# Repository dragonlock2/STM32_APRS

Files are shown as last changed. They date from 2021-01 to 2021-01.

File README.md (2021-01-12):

# STM32 APRS

APRS modulation and demodulation with a UI. Made for STM32L433.

https://matthewtran.dev/2021/01/stm32-aprs/

Potentially reusable modules (.c/.h) in Core/:
* BitFIFO/IntFIFO - FIFO queue implemented with a ring buffer
* SSD1306 - I2C driver for SSD1306 OLED w/ compact font
* Keyboard - ASCII keyboard using T9 button layout
* AFSK - High speed AFSK modulation and demodulation to and from bit streams
* APRS - High speed APRS packet generation and decoding to and from bit streams
* APRSGUI - TUI implementation for displaying and configuring APRS packets

## How to Use

### iPython

ipython/aprs.ipynb is a Python implementation of the APRS encoding and decoding algorithms written for easy conversion to C.

### KiCad

The PCB design files for the hardware are located in kicad/.

### STM32CubeIDE

APRSTest.ioc is a STM32CubeMX configuration file and was used to generate the project starter code in STM32CubeIDE. Everything in Core/ should be copied over to the generated Core/ folder, overwriting as necessary.

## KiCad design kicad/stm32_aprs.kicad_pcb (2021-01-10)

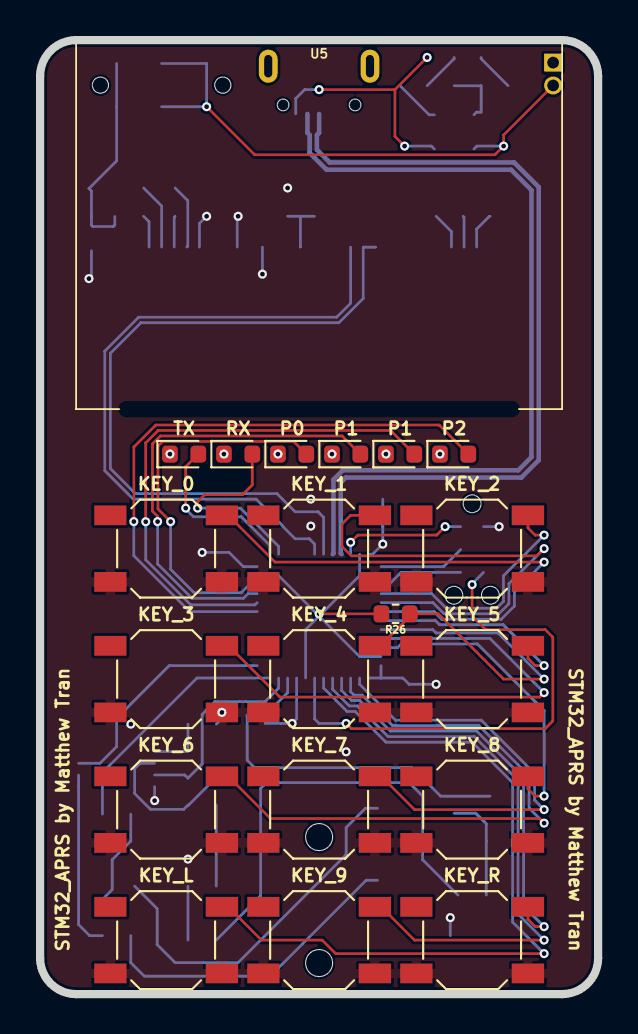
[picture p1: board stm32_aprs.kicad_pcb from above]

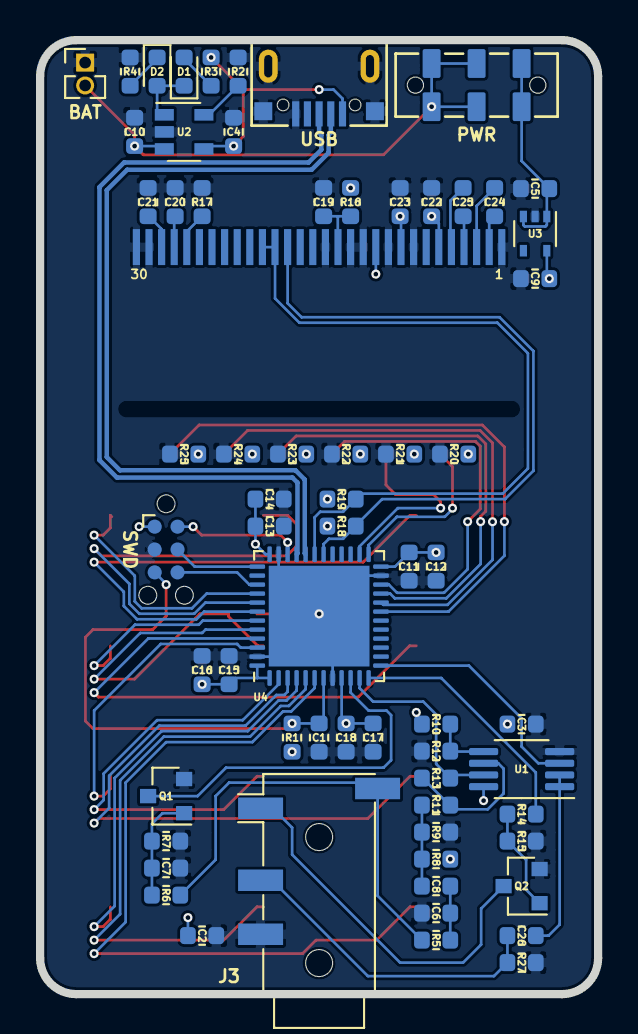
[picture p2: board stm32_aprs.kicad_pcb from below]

Board: 2 copper layers, 31.0 x 53.0 mm, 85 parts (65 on the bottom side), 63 nets.

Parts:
BAT: BAT; PinHeader_1x02_P1.27mm_Vertical
C1, C3, C6, C11, C13, C15, C17, C19: 100n; C_0603_1608Metric
C2, C4, C7, C10, C26: 10u; C_0603_1608Metric
C5, C8, C9, C12, C14, C16, C18, C20, C21, C22, C23, C24, C25: 1u; C_0603_1608Metric
D1: CHRG; LED_0603_1608Metric
D2: FULL; LED_0603_1608Metric
J3: Baofeng; Jack_3.5mm_PJ320D_Horizontal
KEY_0: KEY_0; SW_SPST_SKQG_WithoutStem
KEY_1: KEY_1; SW_SPST_SKQG_WithoutStem
KEY_2: KEY_2; SW_SPST_SKQG_WithoutStem
KEY_3: KEY_3; SW_SPST_SKQG_WithoutStem
KEY_4: KEY_4; SW_SPST_SKQG_WithoutStem
KEY_5: KEY_5; SW_SPST_SKQG_WithoutStem
KEY_6: KEY_6; SW_SPST_SKQG_WithoutStem
KEY_7: KEY_7; SW_SPST_SKQG_WithoutStem
KEY_8: KEY_8; SW_SPST_SKQG_WithoutStem
KEY_9: KEY_9; SW_SPST_SKQG_WithoutStem
KEY_L: KEY_L; SW_SPST_SKQG_WithoutStem
KEY_R: KEY_R; SW_SPST_SKQG_WithoutStem
P0: LED0; LED_0603_1608Metric
P1: LED2; LED_0603_1608Metric
P1#2: LED1; LED_0603_1608Metric
P2: LED3; LED_0603_1608Metric
PWR: PWR_SW; JS202011JAQN
Q1, Q2: DMG2302U; SOT-23
R1, R6, R10, R11, R12, R15, R16, R26: 10k; R_0603_1608Metric
R2, R3, R4, R18, R19, R27: 2.2k; R_0603_1608Metric
R5: 470; R_0603_1608Metric
R7: 22k; R_0603_1608Metric
R8, R9, R20, R21, R22, R23, R24, R25: 1k; R_0603_1608Metric
R13: 47k; R_0603_1608Metric
R14: 22; R_0603_1608Metric
R17: 470k; R_0603_1608Metric
RX: RX; LED_0603_1608Metric
SWD: SWD; Tag-Connect_TC2030-IDC-NL_2x03_P1.27mm_Vertical
TX: TX; LED_0603_1608Metric
U1: MCP6L02x-xMS; MSOP-8_3x3mm_P0.65mm
U2: MCP73831-2-OT; SOT-23-5
U3: MIC5365-3.3YC5; SOT-353_SC-70-5
U4: STM32L433CCUx; QFN-48-1EP_7x7mm_P0.5mm_EP5.6x5.6mm
U5: SSD1306
USB: USB_B_Micro; U254-051N-4BH83-F1B

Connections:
+3V3: C2.2, C3.2, C9.1, C11.1, C12.1, C13.1, C14.1, C15.1, C16.1, C17.1, C18.1, C22.1, C23.1, KEY_0.2, KEY_1.2, KEY_2.2, KEY_3.2, KEY_4.2, KEY_5.2, KEY_6.2, KEY_7.2, KEY_8.2, KEY_9.2, KEY_L.2, KEY_R.2, R1.1, R8.1, R10.2, R16.1, R18.1, R19.1, SWD.1, U1.8, U3.5, U4.1, U4.9, U4.24, U4.36, U4.48, U5.6, U5.9, U5.11
+3V8: BAT.2, C10.1, PWR.2, PWR.3, PWR.5, PWR.6, U2.3
+5V: C4.2, R3.1, U2.4, USB.1
/ADC_IN: R13.1, U1.7, U4.11
/AUDIO_IN: J3.S, R5.2, R6.2
/AUDIO_OUT: C26.1, J3.R1, R27.1
/BOOT0_KEY_4: KEY_4.1, R26.1, U4.44
/DAC_OUT: U1.3, U4.13
/KEY_0: KEY_0.1, U4.42
/KEY_1: KEY_1.1, U4.41
/KEY_2: KEY_2.1, U4.40
/KEY_3: KEY_3.1, U4.45
/KEY_5: KEY_5.1, U4.43
/KEY_6: KEY_6.1, U4.3
/KEY_7: KEY_7.1, U4.2
/KEY_8: KEY_8.1, U4.46
/KEY_9: KEY_9.1, U4.5
/KEY_L: KEY_L.1, U4.6
/KEY_R: KEY_R.1, U4.4
/LED_0: P0.2, U4.22
/LED_1: P1#2.2, U4.21
/LED_2: P1.2, U4.20
/LED_3: P2.2, U4.19
/NRST: C1.1, R1.2, SWD.5, U4.7
/PTT: J3.T, Q2.3
/RX_DET: Q1.3, U4.10
/RX_LED: RX.2, U4.26
/SCL: R18.2, U4.30, U5.18
/SDA: R19.2, U4.31, U5.19, U5.20
/SWCLK: SWD.4, U4.37
/SWDIO: SWD.2, U4.34
/SWO: SWD.6, U4.39
/TX_LED: TX.2, U4.25
/TX_PTT: R14.2, U4.12
/USB_N: U4.32, USB.2
/USB_P: U4.33, USB.3
GND: BAT.1, C1.2, C2.1, C3.1, C4.1, C5.1, C6.2, C7.2, C9.2, C10.2, C11.2, C12.2, C13.2, C14.2, C15.2, C16.2, C17.2, C18.2, C19.2, C20.2, C21.2, C22.2, C23.2, J3.R2, Q1.2, Q2.2, R2.2, R4.1, R7.2, R9.2, R12.1, R15.2, R17.2, R20.1, R21.1, R22.1, R23.1, R24.1, R25.1, R26.2, R27.2, SWD.3, U1.4, U2.2, U3.2, U4.8, U4.23, U4.35, U4.47, U4.49, U5.1, U5.8, U5.10, U5.12, U5.13, U5.15, U5.29, U5.30, USB.5, USB.6
unnamed: C5.2, PWR.1, PWR.4, U3.1, U3.3
unnamed: C6.1, C8.2, R5.1
unnamed: C7.1, Q1.1, R6.1, R7.1
unnamed: C8.1, R8.2, R9.1, R11.2
unnamed: C19.1, R16.2, U5.14
unnamed: C20.1, U5.27
unnamed: C21.1, U5.28
unnamed: C24.1, U5.2
unnamed: C24.2, U5.3
unnamed: C25.1, U5.4
unnamed: C25.2, U5.5
unnamed: C26.2, U1.1, U1.2
unnamed: D1.1, D2.2, U2.1
unnamed: D1.2, R3.2
unnamed: D2.1, R4.2
unnamed: R20.2, TX.1
unnamed: R21.2, RX.1
unnamed: P0.1, R22.2
unnamed: P1#2.1, R23.2
unnamed: P1.1, R24.2
unnamed: P2.1, R25.2
unnamed: Q2.1, R14.1, R15.1
unnamed: R2.1, U2.5
unnamed: R10.1, R12.2, U1.5
unnamed: R11.1, R13.2, U1.6
unnamed: R17.1, U5.26

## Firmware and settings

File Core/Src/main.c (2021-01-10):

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
/* Includes ------------------------------------------------------------------*/
#include "main.h"
#include "usb_device.h"

/* USER CODE BEGIN Includes */

#include "stdio.h"
#include "usbd_cdc_if.h"

#include "BitFIFO.h"
#include "AFSK.h"
#include "APRS.h"
#include "SSD1306.h"
#include "APRSGUI.h"
#include "Keyboard.h"

/* USER CODE END Includes */

ADC_HandleTypeDef hadc1;
DMA_HandleTypeDef hdma_adc1;

DAC_HandleTypeDef hdac1;
DMA_HandleTypeDef hdma_dac_ch1;

I2C_HandleTypeDef hi2c1;
DMA_HandleTypeDef hdma_i2c1_tx;

OPAMP_HandleTypeDef hopamp1;

RNG_HandleTypeDef hrng;

TIM_HandleTypeDef htim2;
TIM_HandleTypeDef htim6;
TIM_HandleTypeDef htim7;

void SystemClock_Config(void);
static void MX_GPIO_Init(void);
static void MX_DMA_Init(void);
static void MX_DAC1_Init(void);
static void MX_TIM6_Init(void);
static void MX_ADC1_Init(void);
static void MX_OPAMP1_Init(void);
static void MX_RNG_Init(void);
static void MX_TIM2_Init(void);
static void MX_TIM7_Init(void);
static void MX_I2C1_Init(void);
/**
  * @brief  The application entry point.
  * @retval int
  */
int main(void)
{
  /* MCU Configuration--------------------------------------------------------*/

  /* Reset of all peripherals, Initializes the Flash interface and the Systick. */
  HAL_Init();

  /* Configure the system clock */
  SystemClock_Config();

  /* Initialize all configured peripherals */
  MX_GPIO_Init();
  MX_DMA_Init();
  MX_DAC1_Init();
  MX_TIM6_Init();
  MX_ADC1_Init();
  MX_OPAMP1_Init();
  MX_RNG_Init();
  MX_TIM2_Init();
  MX_TIM7_Init();
  MX_I2C1_Init();
  MX_USB_DEVICE_Init();
  /* USER CODE BEGIN 2 */

  HAL_OPAMP_Start(&hopamp1);
  AFSK_init();
  APRS_init();

  SSD1306_init();
  APRSGUI_init(&APRS_DEFAULT_PACKET);
  HAL_TIM_Base_Start_IT(&htim7); // update display at ~24FPS

  /* USER CODE END 2 */

  /* Infinite loop */
  /* USER CODE BEGIN WHILE */

  while (1)
  {
    /* USER CODE END WHILE */

    /* USER CODE BEGIN 3 */
	if (APRS_decoded_packet_valid) { // print over usb
		APRS_print(&APRS_decoded_packet);
		APRS_decoded_packet_valid = 0;
	}

	HAL_GPIO_WritePin(TX_LED_GPIO_Port, TX_LED_Pin, AFSK_sending);
	HAL_GPIO_WritePin(RX_LED_GPIO_Port, RX_LED_Pin, !HAL_GPIO_ReadPin(RX_DET_GPIO_Port, RX_DET_Pin));

	HAL_GPIO_WritePin(LED_0_GPIO_Port, LED_0_Pin, Keyboard_page == 0);
	HAL_GPIO_WritePin(LED_1_GPIO_Port, LED_1_Pin, Keyboard_page == 1);
	HAL_GPIO_WritePin(LED_2_GPIO_Port, LED_2_Pin, Keyboard_page == 2);
	HAL_GPIO_WritePin(LED_3_GPIO_Port, LED_3_Pin, Keyboard_page == 3);

	Keyboard_update();

	HAL_Delay(20);
  }
  /* USER CODE END 3 */
}

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
/* USER CODE BEGIN 4 */

int _write(int file, char *ptr, int len) {
//	HAL_UART_Transmit(&huart1, (uint8_t *) ptr, len, HAL_MAX_DELAY);
	CDC_Transmit_FS((uint8_t *) ptr, len);
	return len;
}

/* USER CODE END 4 */
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


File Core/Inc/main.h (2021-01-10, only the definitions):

#define KEY_7_Pin GPIO_PIN_13
#define KEY_7_GPIO_Port GPIOC
#define KEY_6_Pin GPIO_PIN_14
#define KEY_6_GPIO_Port GPIOC
#define KEY_R_Pin GPIO_PIN_15
#define KEY_R_GPIO_Port GPIOC
#define KEY_9_Pin GPIO_PIN_0
#define KEY_9_GPIO_Port GPIOH
#define KEY_L_Pin GPIO_PIN_1
#define KEY_L_GPIO_Port GPIOH
#define RX_DET_Pin GPIO_PIN_0
#define RX_DET_GPIO_Port GPIOA
#define TX_PTT_Pin GPIO_PIN_2
#define TX_PTT_GPIO_Port GPIOA
#define LED_3_Pin GPIO_PIN_1
#define LED_3_GPIO_Port GPIOB
#define LED_2_Pin GPIO_PIN_2
#define LED_2_GPIO_Port GPIOB
#define LED_1_Pin GPIO_PIN_10
#define LED_1_GPIO_Port GPIOB
#define LED_0_Pin GPIO_PIN_11
#define LED_0_GPIO_Port GPIOB
#define TX_LED_Pin GPIO_PIN_12
#define TX_LED_GPIO_Port GPIOB
#define RX_LED_Pin GPIO_PIN_13
#define RX_LED_GPIO_Port GPIOB
#define KEY_2_Pin GPIO_PIN_4
#define KEY_2_GPIO_Port GPIOB
#define KEY_1_Pin GPIO_PIN_5
#define KEY_1_GPIO_Port GPIOB
#define KEY_0_Pin GPIO_PIN_6
#define KEY_0_GPIO_Port GPIOB
#define KEY_5_Pin GPIO_PIN_7
#define KEY_5_GPIO_Port GPIOB
#define KEY_4_Pin GPIO_PIN_3
#define KEY_4_GPIO_Port GPIOH
#define KEY_3_Pin GPIO_PIN_8
#define KEY_3_GPIO_Port GPIOB
#define KEY_8_Pin GPIO_PIN_9
#define KEY_8_GPIO_Port GPIOB

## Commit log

2021-01-10 Added STM32CubeIDE files
2021-01-10 Added kicad files
    [stm32_aprs.kicad_pcb, stm32_aprs.sch]

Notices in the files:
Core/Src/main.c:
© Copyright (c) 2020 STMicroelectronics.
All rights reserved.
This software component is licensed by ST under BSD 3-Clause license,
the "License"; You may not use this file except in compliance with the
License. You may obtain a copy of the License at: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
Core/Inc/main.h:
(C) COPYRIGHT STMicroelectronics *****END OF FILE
